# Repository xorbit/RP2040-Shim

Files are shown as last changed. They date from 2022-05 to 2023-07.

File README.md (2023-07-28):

# RP2040-Shim
Dual-core ARM Cortex M0+ shim for PoE-FeatherWing, functionally equivalent to Feather RP2040.

With parts for the [M4-Shim](https://www.tindie.com/products/silicognition/m4-shim/) scarce,
it seemed wise to come up with a well-supported alternative.

### Description

This is an adaptation of the excellent
[Adafruit Feather RP2040](https://github.com/adafruit/Adafruit-Feather-RP2040-PCB),
redesigned specifically for use with the equally excellent
[PoE-FeatherWing](https://hackaday.io/project/168356-poe-featherwing).

The goal was to create a compact system with Power over Ethernet, Ethernet connectivity and
a powerful processor capable of supporting [CircuitPython](https://circuitpython.org/).
Because of the bulky RJ45 jack and flyback transformer on the PoE-FeatherWing, it was not
possible to mount a traditional Feather on top.  This redesign takes the relevant circuitry
of the Adafruit Feather RP2040 and shapes it so it fits in the gaps between the
tall components of the PoE-FeatherWing.  This way it can be mounted on top for an extremely
compact solution.

The relevant differences versus the Feather RP2040 are omission of the battery support circuitry
(which did not seem necessary in a PoE design), no Qwiic / STEMMA QT connector, no SWD footprint
and 4 MB of SPI flash.
Note also that the board pins are connected differently to the chip so as to fit the tiny board
area available.  When using CircuitPython, the pins use a custom mapping so the names in the
`board` module map to the same board pins as the Feather RP2040, but when using a different
development environment that uses the RP2040 GPIO pin numbers, you will have to adjust them for
this board.

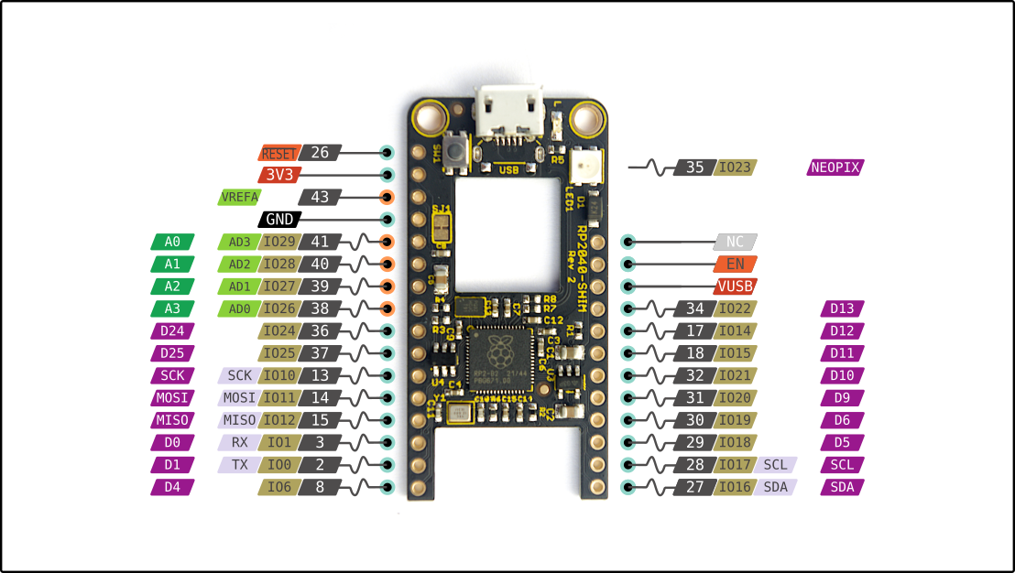
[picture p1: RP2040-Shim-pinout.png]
RP2040-Shim pinout


The hardware is sold with [CircuitPython](https://github.com/adafruit/circuitpython) pre-installed.

### License

This redesign by Silicognition LLC is licensed as Creative Commons Attribution/Share-Alike,
just like the Adafruit Feather RP2040 it is based on.

Original Adafruit license statement:

Feather RP2040

Open source PCB files for Feather RP2040

PCB format is EagleCAD schematic and board layout

For more details, check out the product pages at

    https://www.adafruit.com/products/4884

We are releasing these files so folks can start creating custom designs based on the RP2040 chip. This design has been built and tested successfully

Adafruit invests time and resources providing this open source design, please support Adafruit and open-source hardware by purchasing products from Adafruit!

Designed by Adafruit Industries.
Creative Commons Attribution, Share-Alike license, check license.txt for more information All text above must be included in any redistribution

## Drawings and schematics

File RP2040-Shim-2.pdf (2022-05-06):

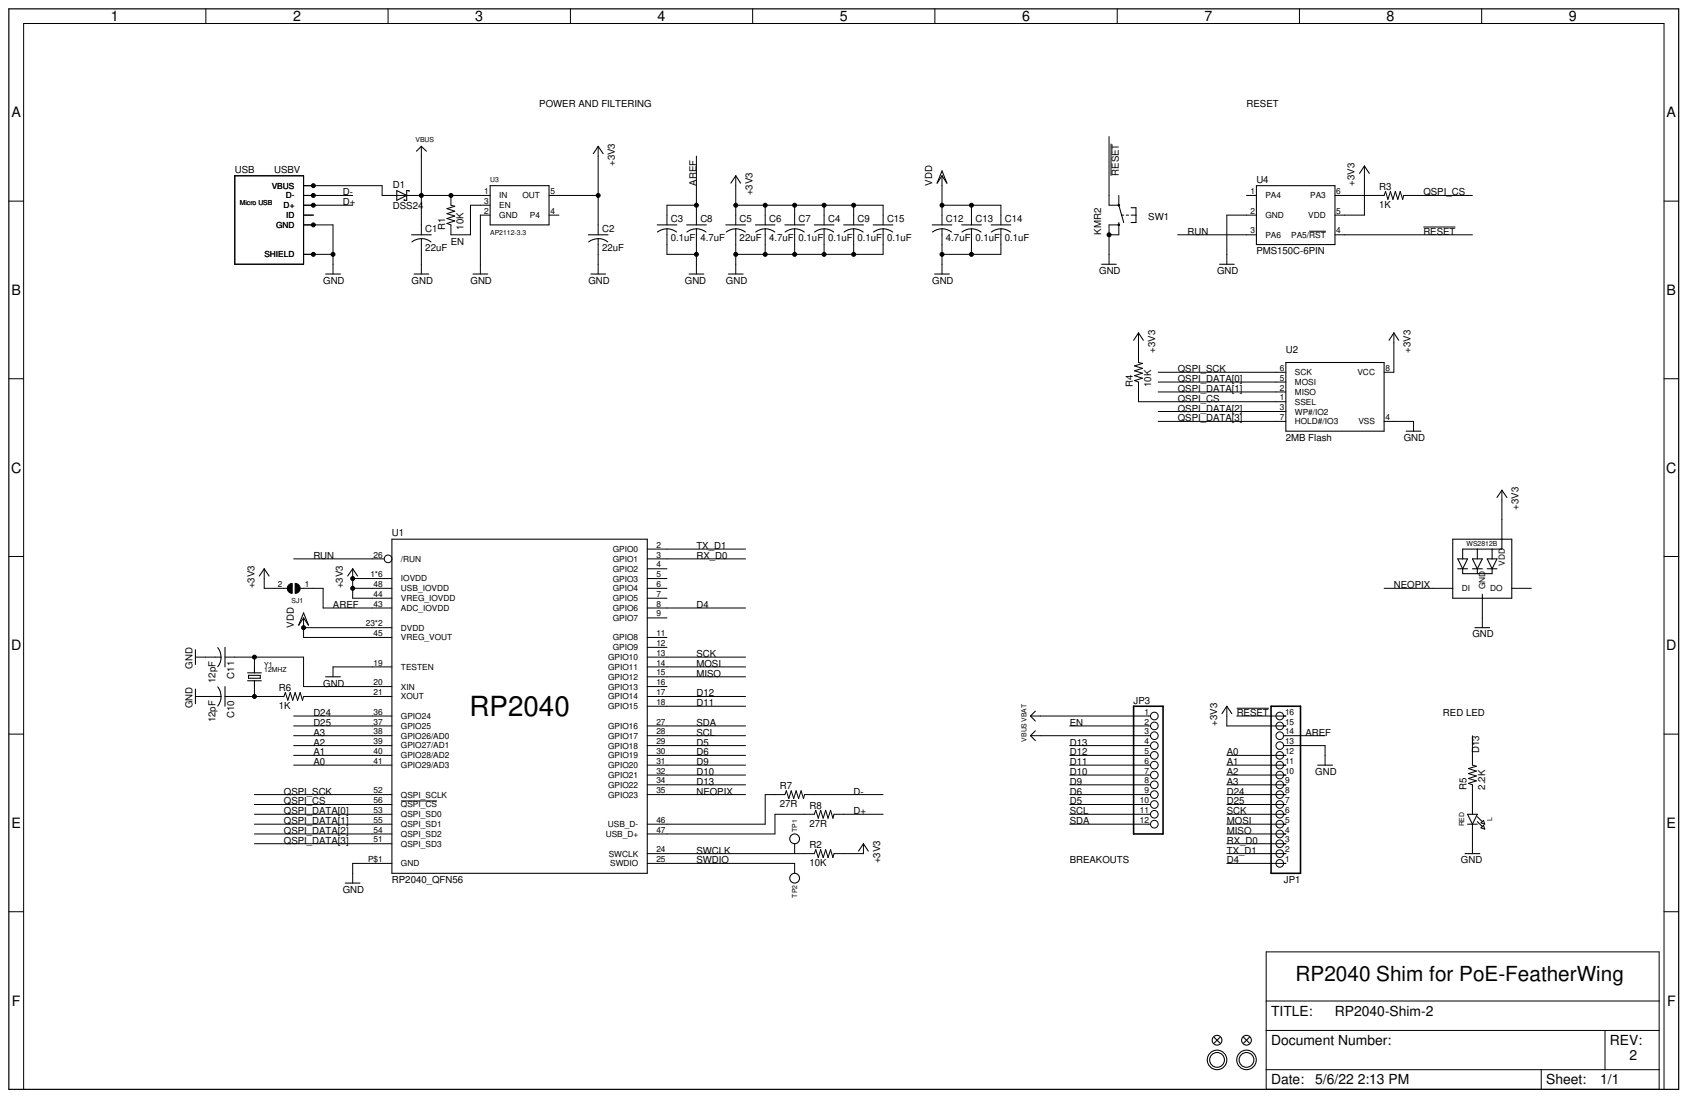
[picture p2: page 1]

RP2040 Shim for PoE-FeatherWing

REV: TITLE: Document Number: RP2040-Shim-2

Date: 5/6/22 2:13 PM | Sheet: 1/1

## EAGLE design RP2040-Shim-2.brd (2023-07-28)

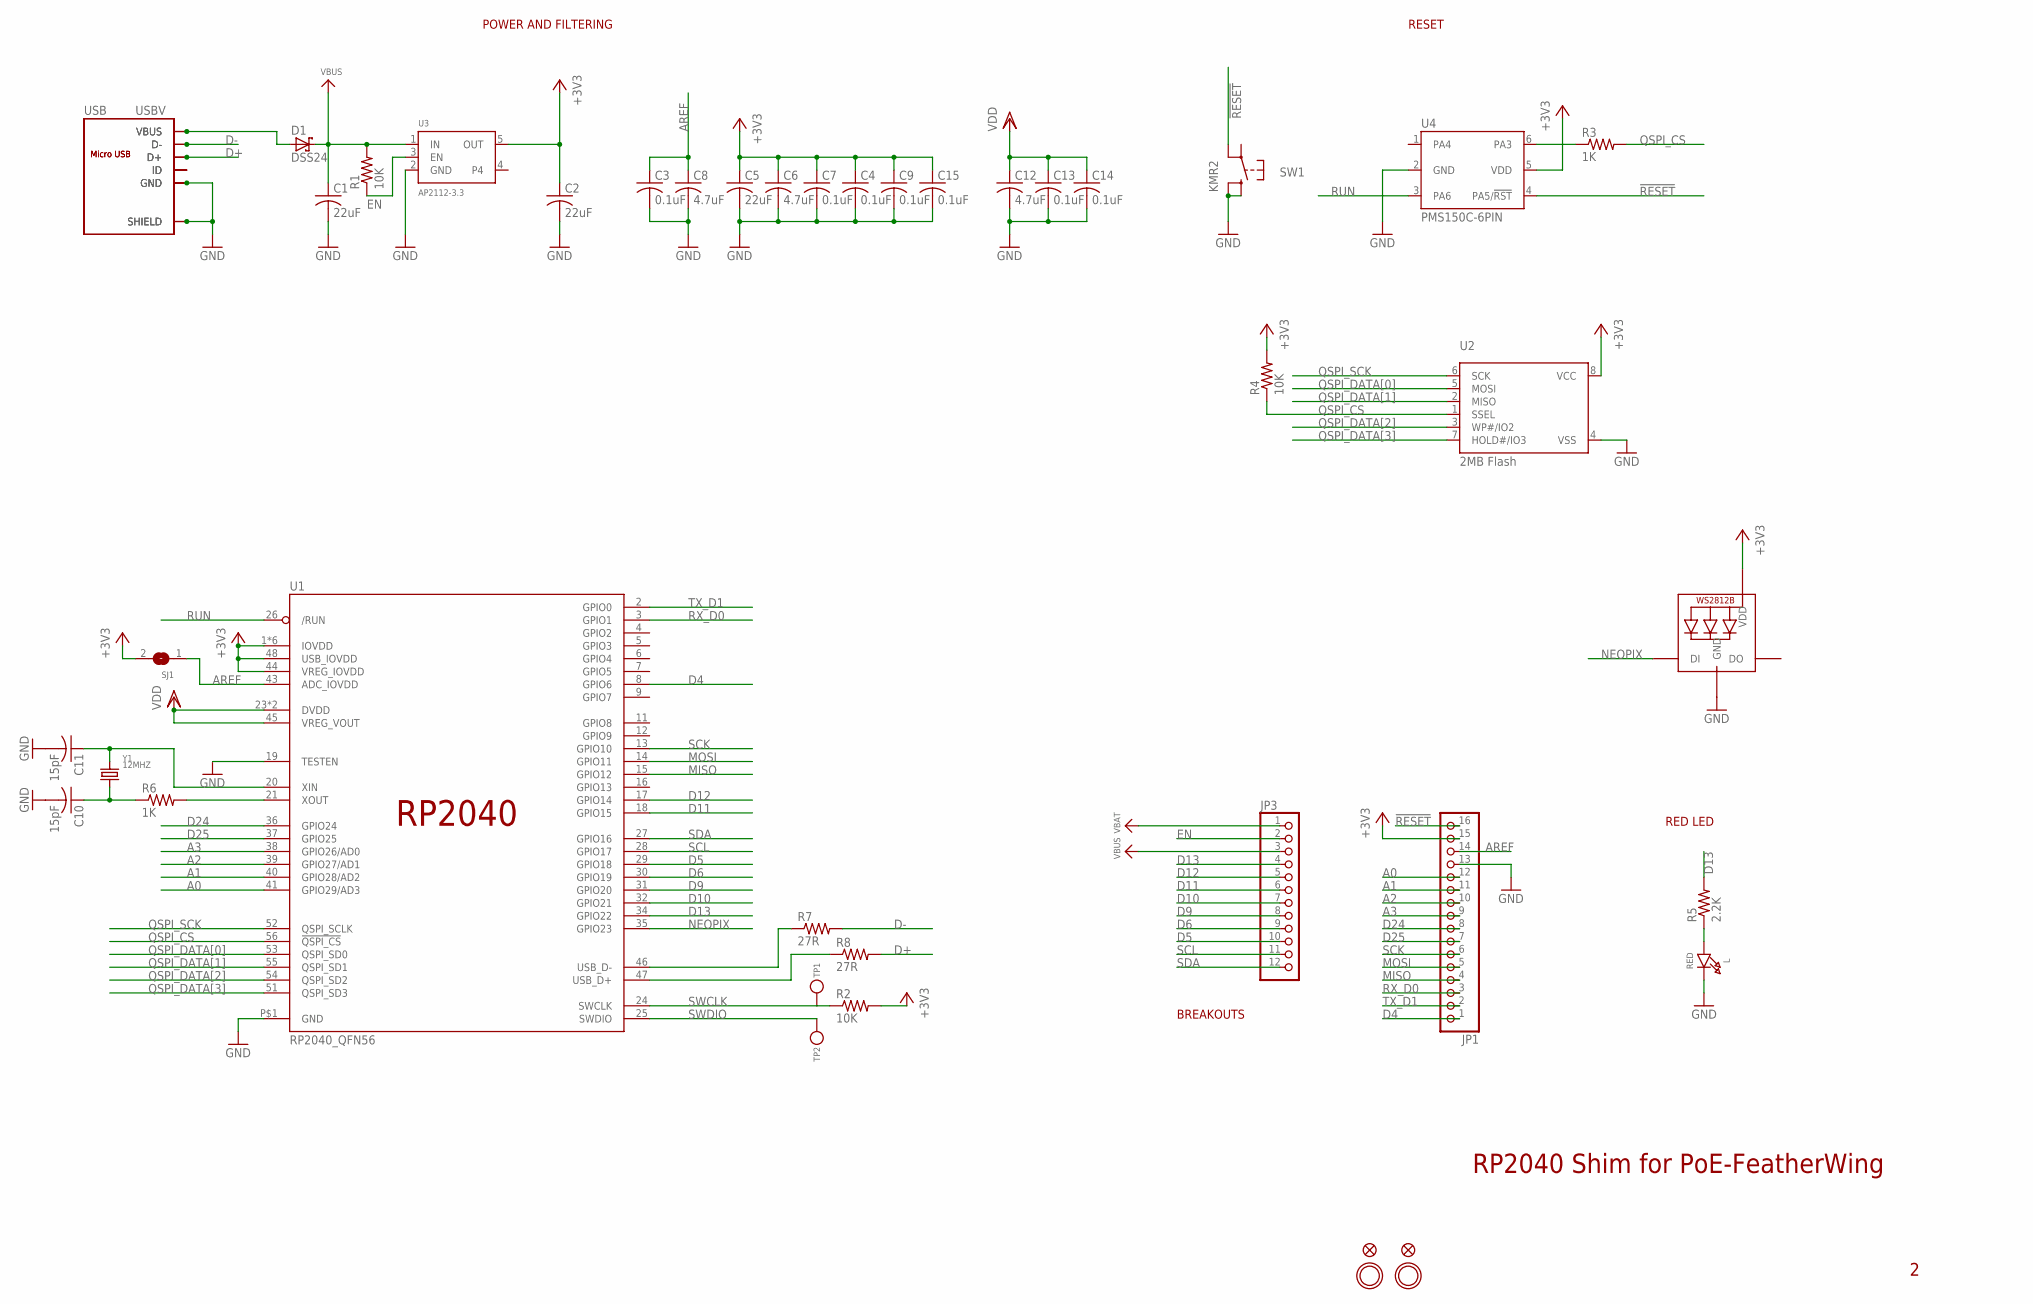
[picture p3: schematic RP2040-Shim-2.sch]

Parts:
C1, C2, C5: 22uF; C0805K
C3, C4, C7, C9, C13, C14, C15: 0.1uF; C0402K
C6, C8, C12: 4.7uF; C0402K
C10, C11: 15pF; C0402K
D1: DSS24; SOD123FL
JP1: HEADER-1X16ROUND; 1X16_ROUND
JP3: HEADER-1X12; 1X12_ROUND
L: RED; CHIPLED_0805_NOOUTLINE
LED1: WS2812B3535; LED3535
R1, R2, R4: 10K; R0402
R3, R6: 1K; R0402
R5: 2.2K; R0402
R7, R8: 27R; R0402
SJ1: SOLDERJUMPERCLOSED; SOLDERJUMPER_CLOSEDWIRE
SW1: KMR2; BTN_KMR2_4.6X2.8
TP1, TP2: TESTPOINTROUND1.5MM; TESTPOINT_ROUND_1.5MM
U1: RP2040_QFN56; QFN56_7MM_REDUCEDEPAD
U2: 2MB Flash; USON8
U3: AP2112-3.3; SOT23-5
U4: PMS150C-6PIN; SOT23-6
U$31, U$32: MOUNTINGHOLE2.5; MOUNTINGHOLE_2.5_PLATED
U$34, U$35: FIDUCIAL_1MM
USB: ZX62-B-5PA; TS-1012E-AC03516
USBV: MICRO-USB-SMD-VERT; U-D-M5DS-W-4
Y1: 12MHZ; CRYSTAL_2.5X2

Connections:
!RESET: JP1.16, SW1.A' (P1), U4.4 (PA5/!RST)
+3V3: C2.1, C4.1, C5.1, C6.1, C7.1, C9.1, C15.1, JP1.15, LED1.2 (VDD), R2.2, R4.2, SJ1.2, U1.1 (IOVDD), U1.10 (IOVDD), U1.22 (IOVDD), U1.33 (IOVDD), U1.42 (IOVDD), U1.44 (VREG_IOVDD), U1.48 (USB_IOVDD), U1.49 (IOVDD), U2.8 (VCC), U3.5 (OUT), U4.5 (VDD)
A0: JP1.12, U1.41 (GPIO29/AD3)
A1: JP1.11, U1.40 (GPIO28/AD2)
A2: JP1.10, U1.39 (GPIO27/AD1)
A3: JP1.9, U1.38 (GPIO26/AD0)
AREF: C3.1, C8.1, JP1.14, SJ1.1, U1.43 (ADC_IOVDD)
D4: JP1.1, U1.8 (GPIO6)
D5: JP3.10, U1.29 (GPIO18)
D6: JP3.9, U1.30 (GPIO19)
D9: JP3.8, U1.31 (GPIO20)
D10: JP3.7, U1.32 (GPIO21)
D11: JP3.6, U1.18 (GPIO15)
D12: JP3.5, U1.17 (GPIO14)
D13: JP3.4, R5.2, U1.34 (GPIO22)
D24: JP1.8, U1.36 (GPIO24)
D25: JP1.7, U1.37 (GPIO25)
D+: R8.2, USB.3 (D+), USBV.3 (D+)
D-: R7.2, USB.2 (D-), USBV.2 (D-)
EN: JP3.2, R1.1, U3.3 (EN)
GND: C1.2, C2.2, C3.2, C4.2, C5.2, C6.2, C7.2, C8.2, C9.2, C10.2, C11.2, C12.2, C13.2, C14.2, C15.2, JP1.13, L.C, LED1.4 (GND), SW1.B (S), SW1.B' (S1), U1.19 (TESTEN), U1.P$1 (GND), U2.4 (VSS), U3.2 (GND), U4.2 (GND), USB.5 (GND), USB.P1 (SHIELD), USB.P2 (SHIELD), USB.P3 (SHIELD), USB.P4 (SHIELD), USB.P5 (SHIELD), USB.P6 (SHIELD), USBV.5 (GND), USBV.MNT1 (SHIELD), USBV.MNT2 (SHIELD), USBV.MNT3 (SHIELD), USBV.MNT4 (SHIELD)
MISO: JP1.4, U1.15 (GPIO12)
MOSI: JP1.5, U1.14 (GPIO11)
unnamed: USB.4 (ID), USBV.4 (ID)
unnamed: L.A, R5.1
unnamed: C10.1, R6.1, Y1.1
unnamed: R6.2, U1.21 (XOUT)
unnamed: C11.1, U1.20 (XIN), Y1.3 (2)
unnamed: R8.1, U1.47 (USB_D+)
unnamed: R7.1, U1.46 (USB_D-)
unnamed: R3.1, U4.6 (PA3)
NEOPIX: LED1.1 (DI), U1.35 (GPIO23)
QSPI_CS: R3.2, R4.1, U1.56 (!QSPI_CS), U2.1 (SSEL)
QSPI_DATA[0]: U1.53 (QSPI_SD0), U2.5 (MOSI)
QSPI_DATA[1]: U1.55 (QSPI_SD1), U2.2 (MISO)
QSPI_DATA[2]: U1.54 (QSPI_SD2), U2.3 (WP#/IO2)
QSPI_DATA[3]: U1.51 (QSPI_SD3), U2.7 (HOLD#/IO3)
QSPI_SCK: U1.52 (QSPI_SCLK), U2.6 (SCK)
RUN: U1.26 (/RUN), U4.3 (PA6)
RX_D0: JP1.3, U1.3 (GPIO1)
SCK: JP1.6, U1.13 (GPIO10)
SCL: JP3.11, U1.28 (GPIO17)
SDA: JP3.12, U1.27 (GPIO16)
SWCLK: R2.1, TP1.P$1, U1.24 (SWCLK)
SWDIO: TP2.P$1, U1.25 (SWDIO)
TX_D1: JP1.2, U1.2 (GPIO0)
VBAT: JP3.1
VBUS: C1.1, D1.C, JP3.3, R1.2, U3.1 (IN)
VBUSEXT: D1.A, USB.1 (VBUS), USBV.1 (VBUS)
VDD: C12.1, C13.1, C14.1, U1.23 (DVDD), U1.45 (VREG_VOUT), U1.50 (DVDD)

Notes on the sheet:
POWER AND FILTERING
RESET
BREAKOUTS
RED LED
RP2040 Shim for PoE-FeatherWing

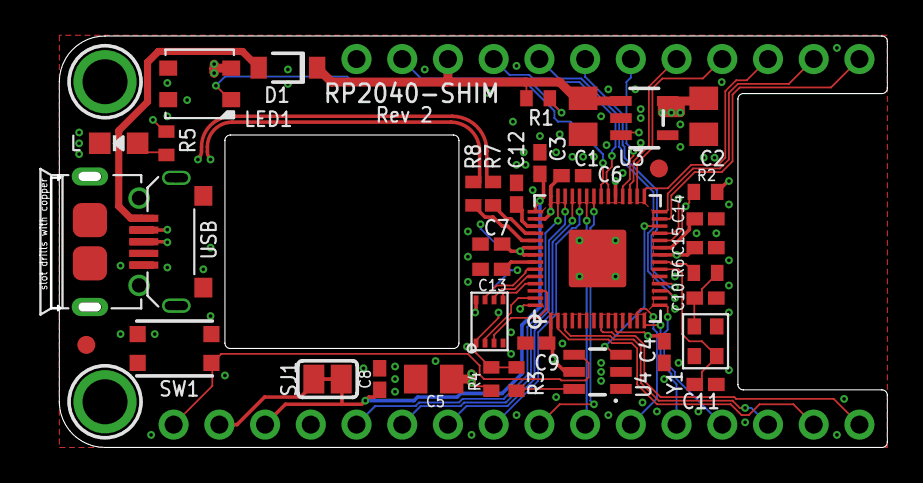
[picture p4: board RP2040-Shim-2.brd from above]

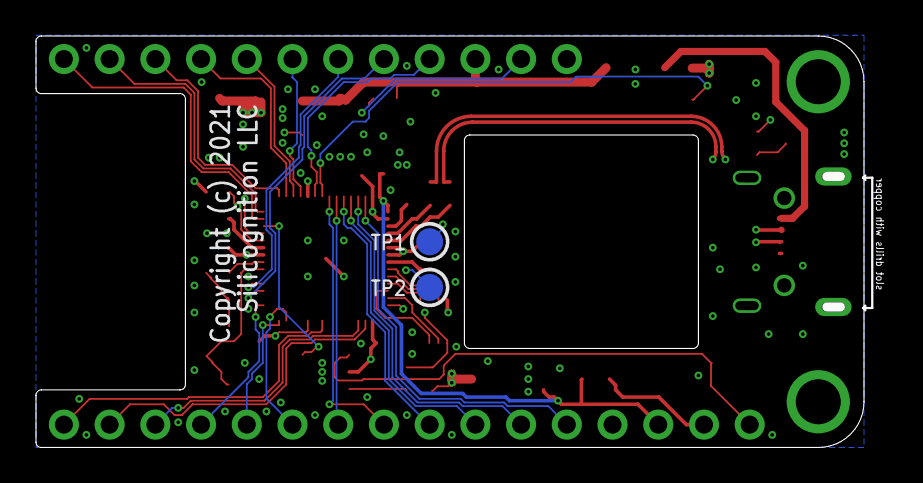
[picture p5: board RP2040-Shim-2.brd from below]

Board: 4 copper layers, 46.0 x 22.9 mm, 43 parts (2 on the bottom side), 49 nets.

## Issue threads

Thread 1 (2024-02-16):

Physical Pinout Of PoE FeatherWing <-> RP2040-Shim

the-wondersmith, 2024-02-16:
Heya! This is less an "issue" and more a question.

I'm working on an embedded system management... _thing_ using your RP2040-shim and PoE FeatherWing boards. Minor twist - I'm writing the firmware in rust (not python or arduino/c++).

I'm having trouble figuring out the physical pin connections between the shim and poe featherwing boards, which in turn is making me doubt whether or not I've got the correct pin numbers configured.

At the moment, this is how I have it -

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

Is ^ that even _remotely_ correct?

xorbit, 2024-02-16:
Hi Mark,
Partially but not entirely correct. :)  You can refer to this table here:
https://silicognition.com/Products/poe-featherwing/#feather-footprint

The problem being that pin numbering is probably not standardized for Feather. ;)  For the referenced table, pin 1 is the one closest to the button, and wraps around to end at the RGB LED.
Reset is not brought out to a pin or solder jumper, only to a solder pad if you need to hook it up.  By default, it is triggered by an RC circuit on power up.
To connect IRQ to pin 24 you need to bridge the solder jumper SJIRQ.  Or run it from the solder pad to any pin you like instead.

the-wondersmith, 2024-02-16:
@xorbit So just to make double-extra-sure, this?

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

xorbit, 2024-02-16:
Yes! 👍

the-wondersmith, 2024-02-16:
Awesome! Thank you!

the-wondersmith, 2024-02-19:
@xorbit Apologies for the oversight, but I figured out the issue 😅.

What pin number on the RP2040 is the `EN`  pin connected to here?

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

xorbit, 2024-02-19:
As on most Feather boards, it is connected to the LDO enable pin that turns incoming 5V nominal (from USB or PoE, if connected to a PoE-FeatherWing) into 3.3V for the system.  It's not connected to the RP2040.  Pulling it low by external means would turn the 3.3V power to the system off.

Closed 2024-02-19.

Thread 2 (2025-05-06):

Incorrect pins in Arduino board variant

JetForMe, 2025-05-06:
In the Arduino RPi Pico RP2040 Board v4.5.3 (the latest afaict), for the RP2040 Shim, the I2C pins have at least one error:

```
// Wire
#define __WIRE0_DEVICE i2c0
#define PIN_WIRE0_SDA  (16u)
#define PIN_WIRE0_SCL  (17u)
#define __WIRE1_DEVICE i2c1
#define PIN_WIRE1_SDA  (31u)
#define PIN_WIRE1_SCL  (31u)
```

`PIN_WIRE1_SDA` and `PIN_WIRE1_SCL` are set to the same pin number.

xorbit, 2025-05-06:
I believe the pin value 31u is intended to indicate that this pin is not implemented.  Only one I2C bus is implemented for the board.

JetForMe, 2025-05-07:
Ah gotcha. I've seen -1 used in ESP32, but not sure if that's used everywhere.

Closed 2025-05-07.

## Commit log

2022-06-14 Update README to my fork instead of upstream CircuitPython
    This shows the changes to be made to add the board.
2023-01-19 Update README.md
    Point to official Adafruit CircuitPython repo.
2023-07-28 Update osc caps to 15 pF, add pinout diagram
    [RP2040-Shim-2.brd, RP2040-Shim-2.sch]

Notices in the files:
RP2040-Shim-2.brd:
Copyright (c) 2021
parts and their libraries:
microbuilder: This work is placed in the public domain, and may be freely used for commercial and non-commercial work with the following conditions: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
